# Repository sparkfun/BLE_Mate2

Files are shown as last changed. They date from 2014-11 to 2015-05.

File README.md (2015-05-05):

SparkFun BLE Mate 2
========================================

SparkFun BLE Mate 2

[*SparkFun BLE Mate 2 (WRL-13019)*](https://www.sparkfun.com/products/13019)

Repository Contents
-------------------

* **/Arduino** - All Arduino libraries and board examples
* **/Hardware** - All Eagle design files (.brd, .sch)
* **/Production** - Test bed files and production panel files

Version History
---------------
* [vH10L1.0.0](https://github.com/sparkfun/BLE_Mate2/tree/vH10L1.0.0) - Product version 10, library 1.0.0

License Information
-------------------
The hardware is released under [Creative Commons ShareAlike 4.0 International](https://creativecommons.org/licenses/by-sa/4.0/).
The code is beerware; if you see me (or any other SparkFun employee) at the local, and you've found our code helpful, please buy us a round!

Distributed as-is; no warranty is given.

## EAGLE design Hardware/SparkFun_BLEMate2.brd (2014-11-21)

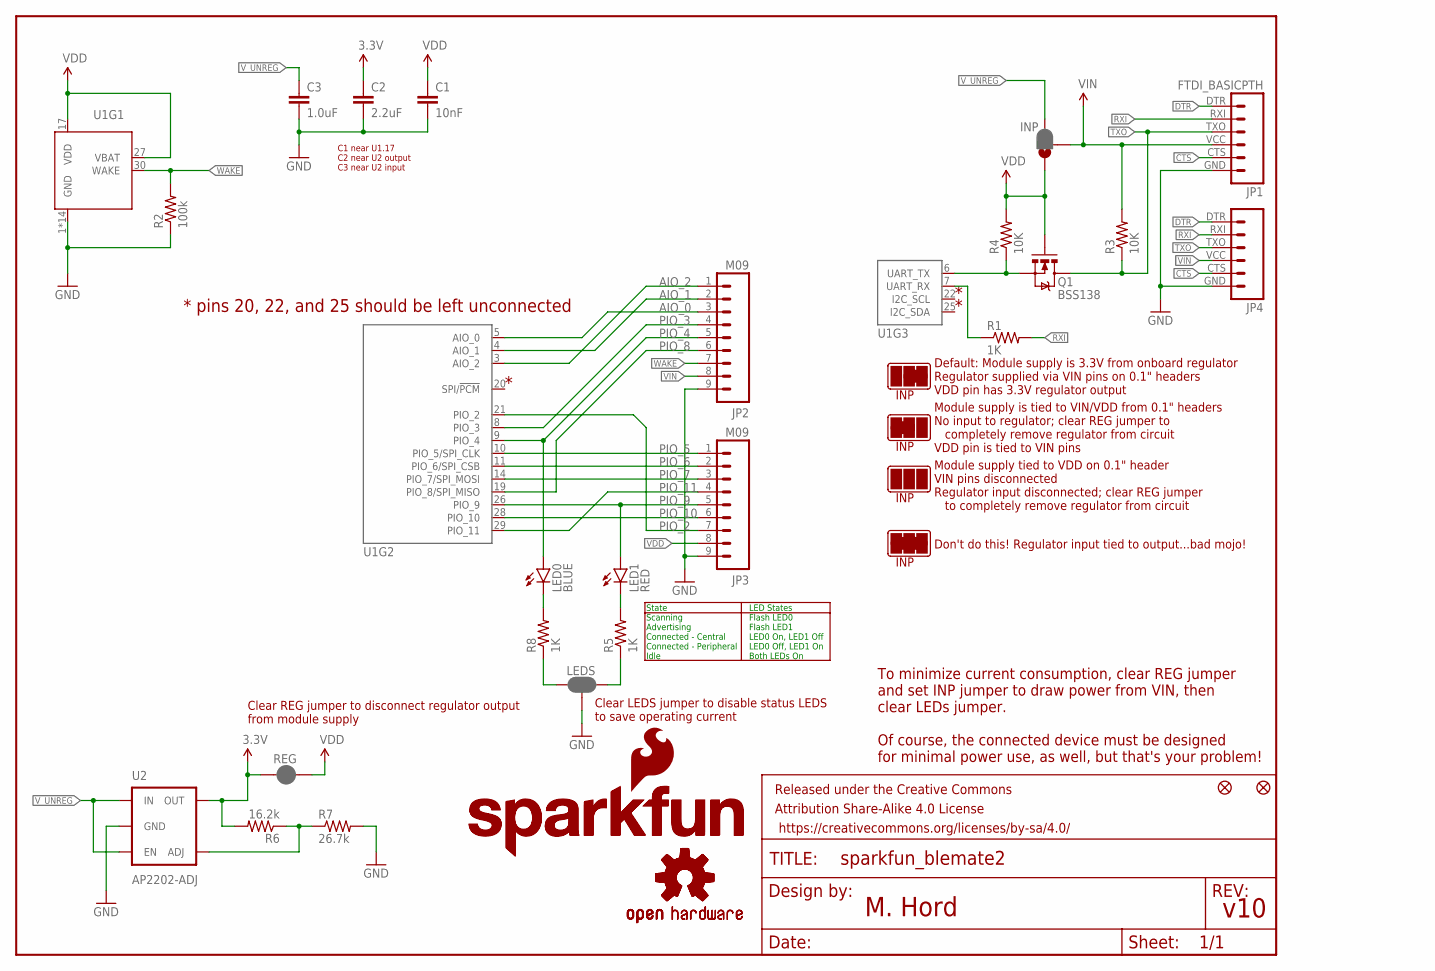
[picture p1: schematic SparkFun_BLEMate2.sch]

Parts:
C1: 10nF; 0603-CAP
C2: 2.2uF; 0603-CAP
C3: 1.0uF; 0603-CAP
FID1, FID2: FIDUCIAL1X2; FIDUCIAL-1X2
FRAME1: FRAME-LETTER; CREATIVE_COMMONS
INP: JUMPER-PAD-3-2OF3_NC_BY_PASTE; PAD-JUMPER-3-2OF3_NC_BY_PASTE_YES_SILK_FULL_BOX
JP1: FTDI_BASICPTH; FTDI_BASIC
JP2, JP3: M09; 1X09
JP4: M06SIP; 1X06
LED0: BLUE; LED-0603
LED1: RED; LED-0603
LEDS: JUMPER-PAD-3-NC_BY_PASTE; PAD-JUMPER-3-NC_BY_PASTE_YES_SILK_FULL_BOX
LOGO1: SFE_LOGO_NAME.1_INCH; SFE_LOGO_NAME_.1
LOGO2, LOGO4: OSHW-LOGOS; OSHW-LOGO-S
LOGO3: SFE_LOGO_NAME_FLAME.1_INCH; SFE_LOGO_NAME_FLAME_.1
Q1: BSS138; SOT23
R1, R5, R8: 1K; 0603-RES
R2: 100k; 0603-RES
R3, R4: 10K; 0603-RES
R6: 16.2k; 0603-RES
R7: 26.7k; 0603-RES
REG: JUMPER-PAD-2-NC_BY_PASTE; PAD-JUMPER-2-NC_BY_PASTE_YES_SILK
U1: BC118
U2: AP2202-ADJ; SOT23-5

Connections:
3.3V: C2.1, R6.2, REG.1, U2.5 (OUT)
AIO_0: JP2.3, U1.5 (AIO_0)
AIO_1: JP2.2, U1.4 (AIO_1)
AIO_2: JP2.1, U1.3 (AIO_2)
CTS: JP1.CTS (5), JP4.CTS (5)
DTR: JP1.DTR (1), JP4.DTR (1)
GND: C1.2, C2.2, C3.2, JP1.GND (6), JP2.9, JP3.9, JP4.GND (6), LEDS.2, R2.1, R7.2, U1.1 (GND), U1.2 (GND), U1.12 (GND), U1.13 (GND), U1.15 (GND), U1.16 (GND), U1.18 (GND), U1.23 (GND), U1.24 (GND), U1.31 (GND), U1.32 (GND), U1.33 (GND), U1.34 (GND), U1.35 (GND), U2.2 (GND)
unnamed: R1.1, U1.7 (UART_RX)
unnamed: R6.1, R7.1, U2.4 (ADJ)
unnamed: Q1.2 (S), R4.1, U1.6 (UART_TX)
unnamed: LEDS.1, R8.1
unnamed: LEDS.3, R5.1
unnamed: LED0.C, R8.2
unnamed: LED1.C, R5.2
PIO_2: JP3.7, U1.21 (PIO_2)
PIO_3: JP2.4, U1.8 (PIO_3)
PIO_4: JP2.5, LED0.A, U1.9 (PIO_4)
PIO_5: JP3.1, U1.10 (PIO_5/SPI_CLK)
PIO_6: JP3.2, U1.11 (PIO_6/SPI_CSB)
PIO_7: JP3.3, U1.14 (PIO_7/SPI_MOSI)
PIO_8: JP2.6, U1.19 (PIO_8/SPI_MISO)
PIO_9: JP3.5, LED1.A, U1.26 (PIO_9)
PIO_10: JP3.6, U1.28 (PIO_10)
PIO_11: JP3.4, U1.29 (PIO_11)
RXI: JP1.RXI (2), JP4.RXI (2), R1.2
TXO: JP1.TXO (3), JP4.TXO (3), Q1.3 (D), R3.1
VDD: C1.1, INP.1, JP3.8, Q1.1 (G), R4.2, REG.2, U1.17 (VDD), U1.27 (VBAT)
VIN: INP.2, JP1.VCC (4), JP2.8, JP4.VCC (4), R3.2
V_UNREG: C3.1, INP.3, U2.1 (IN), U2.3 (EN)
WAKE: JP2.7, R2.2, U1.30 (WAKE)

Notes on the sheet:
State Scanning Advertising Connected - Central Connected - Peripheral Idle
LED States Flash LED0 Flash LED1 LED0 On, LED1 Off LED0 Off, LED1 On Both LEDs On
C1 near U1.17 C2 near U2 output C3 near U2 input
INP
Default: Module supply is 3.3V from onboard regulator Regulator supplied via VIN pins on 0.1" headers VDD pin has 3.3V regulator output
Module supply is tied to VIN/VDD from 0.1" headers No input to regulator; clear REG jumper to completely remove regulator from circuit VDD pin is tied to VIN pins
Module supply tied to VDD on 0.1" header VIN pins disconnected Regulator input disconnected; clear REG jumper to completely remove regulator from circuit
Don't do this! Regulator input tied to output...bad mojo!
Clear LEDS jumper to disable status LEDS to save operating current
Clear REG jumper to disconnect regulator output from module supply
* pins 20, 22, and 25 should be left unconnected
To minimize current consumption, clear REG jumper and set INP jumper to draw power from VIN, then clear LEDs jumper. Of course, the connected device must be designed for minimal power use, as well, but that's your problem!
M. Hord
v10

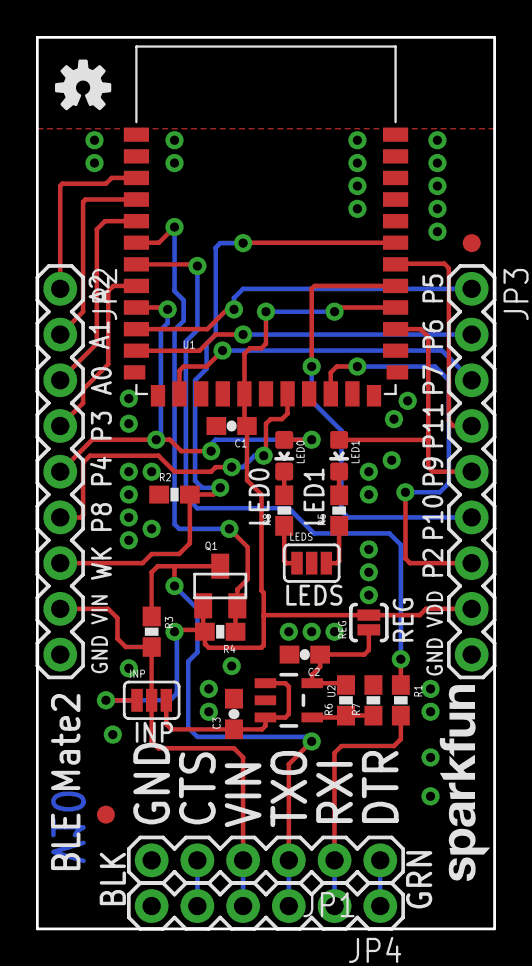
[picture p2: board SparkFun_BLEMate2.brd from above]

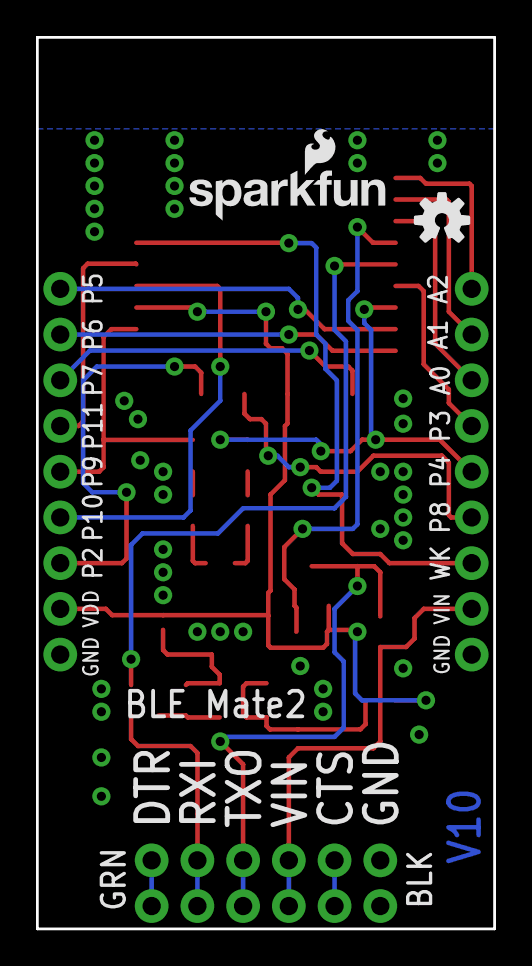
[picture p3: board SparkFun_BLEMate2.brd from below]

Board: 2 copper layers, 25.4 x 49.5 mm, 30 parts (2 on the bottom side), 30 nets.

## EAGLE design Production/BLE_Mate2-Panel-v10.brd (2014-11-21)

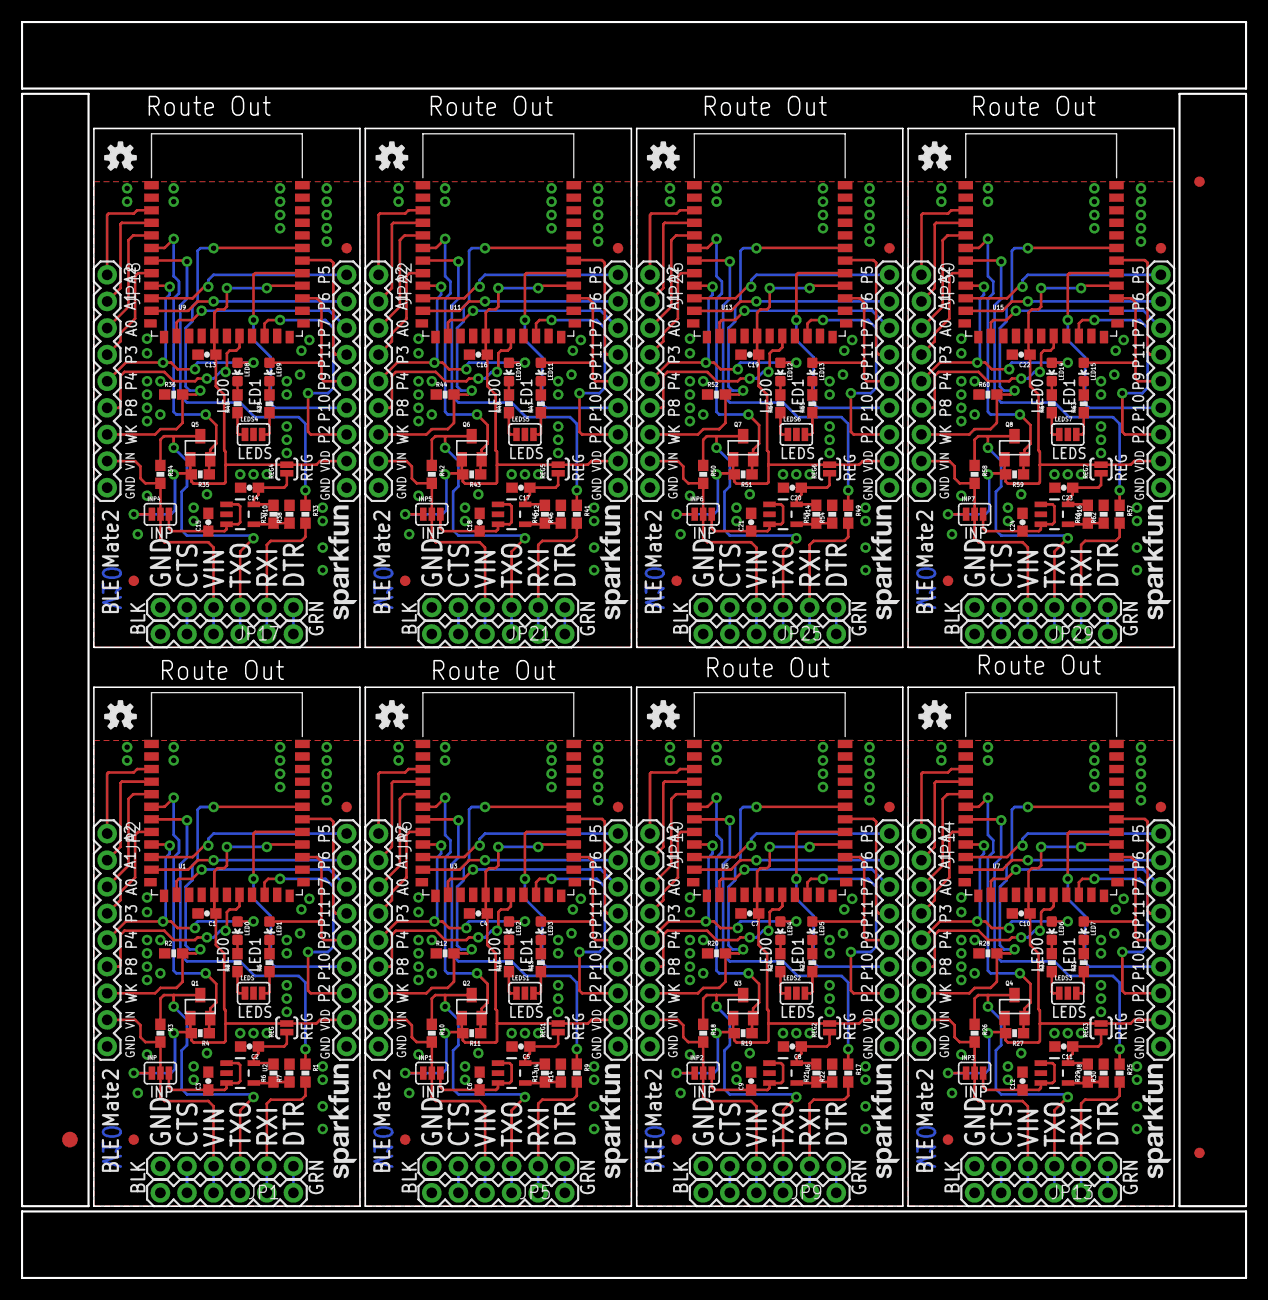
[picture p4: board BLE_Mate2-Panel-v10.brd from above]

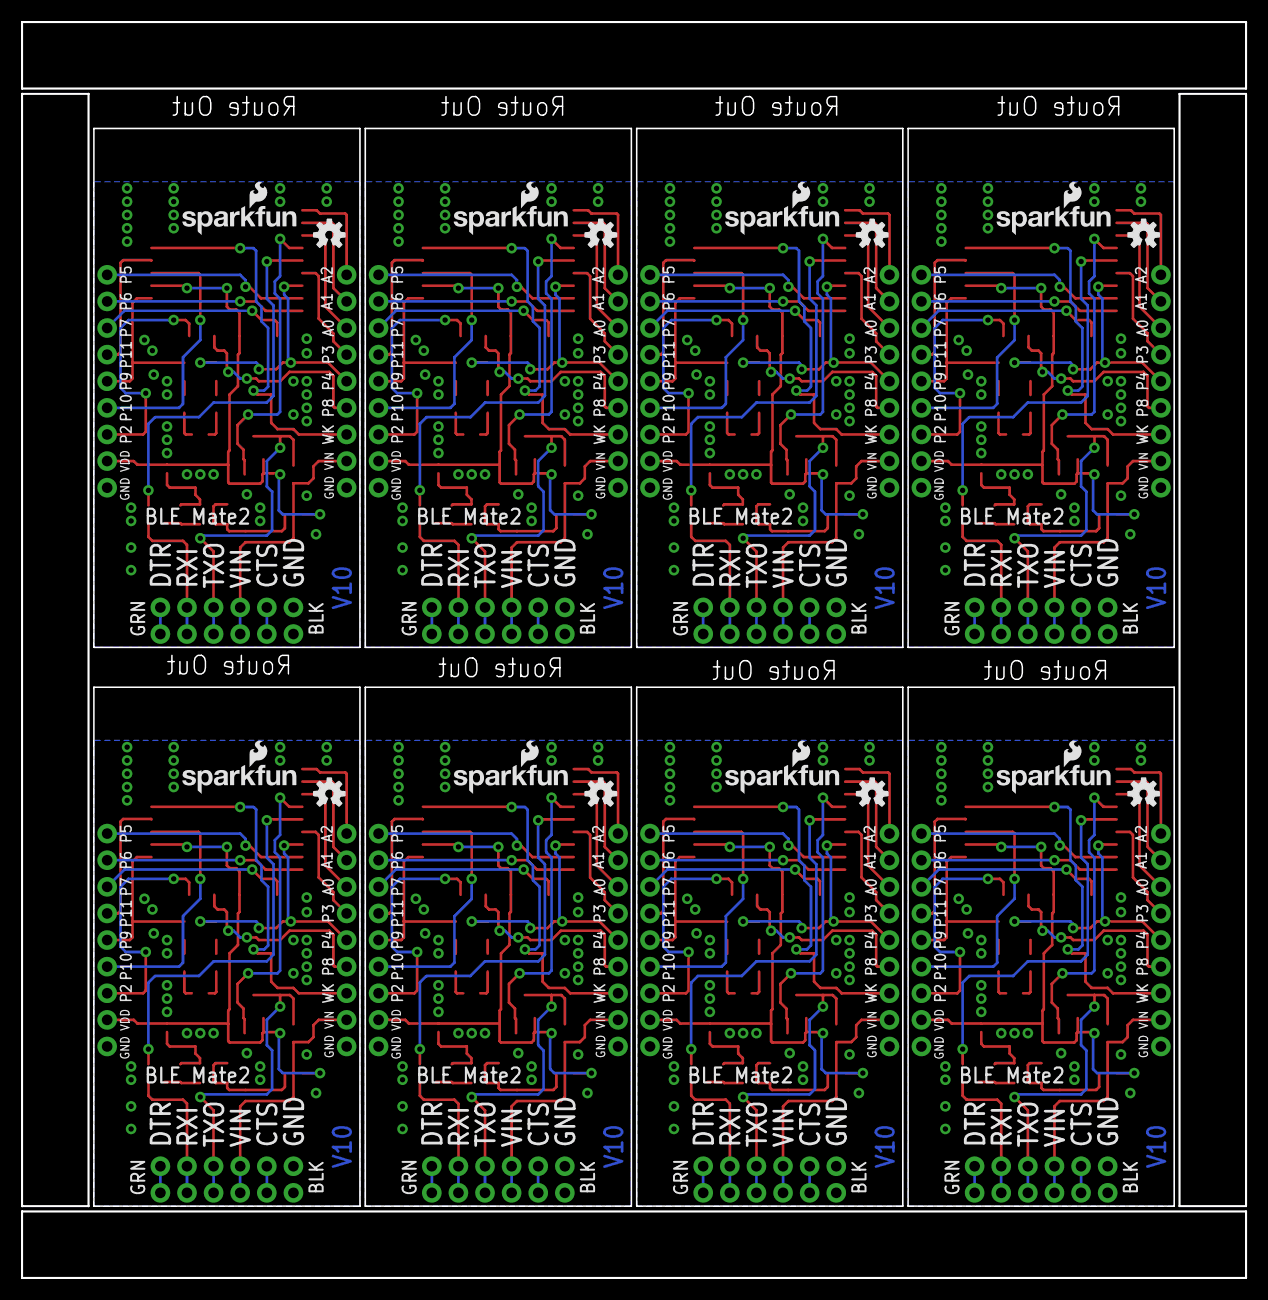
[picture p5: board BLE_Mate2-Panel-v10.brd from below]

Board: 2 copper layers, 116.8 x 119.9 mm, 235 parts (16 on the bottom side), 240 nets.

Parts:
C1, C4, C7, C10, C13, C16, C19, C22: 10nF; 0603-CAP
C2, C5, C8, C11, C14, C17, C20, C23: 2.2uF; 0603-CAP
C3, C6, C9, C12, C15, C18, C21, C24: 1.0uF; 0603-CAP
E$1: FIDUCIAL-1.5X3
E$4, E$5: FIDUCIAL-1X2
FID1, FID2, FID3, FID4, FID5, FID6, FID7, FID8, FID9, FID10, FID11, FID12, FID13, FID14, FID15, FID16: FIDUCIAL1X2; FIDUCIAL-1X2
INP, INP1, INP2, INP3, INP4, INP5, INP6, INP7: JUMPER-PAD-3-2OF3_NC_BY_PASTE; PAD-JUMPER-3-2OF3_NC_BY_PASTE_YES_SILK_FULL_BOX
JP1, JP5, JP9, JP13, JP17, JP21, JP25, JP29: FTDI_BASICPTH; FTDI_BASIC
JP2, JP3, JP6, JP7, JP10, JP11, JP14, JP15, JP18, JP19, JP22, JP23, JP26, JP27, JP30, JP31: M09; 1X09
JP4, JP8, JP12, JP16, JP20, JP24, JP28, JP32: 1X06
LED0, LED2, LED4, LED6, LED8, LED10, LED12, LED14: BLUE; LED-0603
LED1, LED3, LED5, LED7, LED9, LED11, LED13, LED15: RED; LED-0603
LEDS, LEDS1, LEDS2, LEDS3, LEDS4, LEDS5, LEDS6, LEDS7: JUMPER-PAD-3-NC_BY_PASTE; PAD-JUMPER-3-NC_BY_PASTE_YES_SILK_FULL_BOX
LOGO1, LOGO5, LOGO9, LOGO13, LOGO17, LOGO21, LOGO25, LOGO29: SFE_LOGO_NAME.1_INCH; SFE_LOGO_NAME_.1
LOGO2, LOGO4, LOGO6, LOGO8, LOGO10, LOGO12, LOGO14, LOGO16, LOGO18, LOGO20, LOGO22, LOGO24, LOGO26, LOGO28, LOGO30, LOGO32: OSHW-LOGOS; OSHW-LOGO-S
LOGO3, LOGO7, LOGO11, LOGO15, LOGO19, LOGO23, LOGO27, LOGO31: SFE_LOGO_NAME_FLAME.1_INCH; SFE_LOGO_NAME_FLAME_.1
Q1, Q2, Q3, Q4, Q5, Q6, Q7, Q8: BSS138; SOT23
R1, R5, R8, R9, R15, R16, R17, R23, R24, R25, R31, R32, R33, R39, R40, R41, R47, R48, R49, R55, R56, R57, R63, R64: 1K; 0603-RES
R2, R12, R20, R28, R36, R44, R52, R60: 100k; 0603-RES
R3, R4, R10, R11, R18, R19, R26, R27, R34, R35, R42, R43, R50, R51, R58, R59: 10K; 0603-RES
R6, R13, R21, R29, R37, R45, R53, R61: 16.2k; 0603-RES
R7, R14, R22, R30, R38, R46, R54, R62: 26.7k; 0603-RES
REG, REG1, REG2, REG3, REG4, REG5, REG6, REG7: JUMPER-PAD-2-NC_BY_PASTE; PAD-JUMPER-2-NC_BY_PASTE_YES_SILK
U1, U3, U5, U7, U9, U11, U13, U15: BC118
U2, U4, U6, U8, U10, U12, U14, U16: AP2202-ADJ; SOT23-5

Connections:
3.3V: C2.1, R6.2, REG.1, U2.5
3.3V1: C5.1, R13.2, REG1.1, U4.5
3.3V2: C8.1, R21.2, REG2.1, U6.5
3.3V3: C11.1, R29.2, REG3.1, U8.5
3.3V4: C14.1, R37.2, REG4.1, U10.5
3.3V5: C17.1, R45.2, REG5.1, U12.5
3.3V6: C20.1, R53.2, REG6.1, U14.5
3.3V7: C23.1, R61.2, REG7.1, U16.5
AIO_0: JP2.3, U1.5
AIO_1: JP2.2, U1.4
AIO_2: JP2.1, U1.3
AIO_3: JP6.1, U3.3
AIO_4: JP6.2, U3.4
AIO_5: JP6.3, U3.5
AIO_6: JP10.1, U5.3
AIO_7: JP10.2, U5.4
AIO_8: JP10.3, U5.5
AIO_9: JP14.1, U7.3
AIO_10: JP14.2, U7.4
AIO_11: JP14.3, U7.5
AIO_12: JP18.1, U9.3
AIO_13: JP18.2, U9.4
AIO_14: JP18.3, U9.5
AIO_15: JP22.1, U11.3
AIO_16: JP22.2, U11.4
AIO_17: JP22.3, U11.5
AIO_18: JP26.1, U13.3
AIO_19: JP26.2, U13.4
AIO_20: JP26.3, U13.5
AIO_21: JP30.1, U15.3
AIO_22: JP30.2, U15.4
AIO_23: JP30.3, U15.5
CTS: JP1.CTS, JP4.CTS
CTS1: JP5.CTS, JP8.CTS
CTS2: JP9.CTS, JP12.CTS
CTS3: JP13.CTS, JP16.CTS
CTS4: JP17.CTS, JP20.CTS
CTS5: JP21.CTS, JP24.CTS
CTS6: JP25.CTS, JP28.CTS
CTS7: JP29.CTS, JP32.CTS
DTR: JP1.DTR, JP4.DTR
DTR1: JP5.DTR, JP8.DTR
DTR2: JP9.DTR, JP12.DTR
DTR3: JP13.DTR, JP16.DTR
DTR4: JP17.DTR, JP20.DTR
DTR5: JP21.DTR, JP24.DTR
DTR6: JP25.DTR, JP28.DTR
DTR7: JP29.DTR, JP32.DTR
GND: C1.2, C2.2, C3.2, JP1.GND, JP2.9, JP3.9, JP4.GND, LEDS.2, R2.1, R7.2, U1.1, U1.2, U1.12, U1.13, U1.15, U1.16, U1.18, U1.23, U1.24, U1.31, U1.32, U1.33, U1.34, U1.35, U2.2
GND1: C4.2, C5.2, C6.2, JP5.GND, JP6.9, JP7.9, JP8.GND, LEDS1.2, R12.1, R14.2, U3.1, U3.2, U3.12, U3.13, U3.15, U3.16, U3.18, U3.23, U3.24, U3.31, U3.32, U3.33, U3.34, U3.35, U4.2
GND2: C7.2, C8.2, C9.2, JP9.GND, JP10.9, JP11.9, JP12.GND, LEDS2.2, R20.1, R22.2, U5.1, U5.2, U5.12, U5.13, U5.15, U5.16, U5.18, U5.23, U5.24, U5.31, U5.32, U5.33, U5.34, U5.35, U6.2
GND3: C10.2, C11.2, C12.2, JP13.GND, JP14.9, JP15.9, JP16.GND, LEDS3.2, R28.1, R30.2, U7.1, U7.2, U7.12, U7.13, U7.15, U7.16, U7.18, U7.23, U7.24, U7.31, U7.32, U7.33, U7.34, U7.35, U8.2
GND4: C13.2, C14.2, C15.2, JP17.GND, JP18.9, JP19.9, JP20.GND, LEDS4.2, R36.1, R38.2, U9.1, U9.2, U9.12, U9.13, U9.15, U9.16, U9.18, U9.23, U9.24, U9.31, U9.32, U9.33, U9.34, U9.35, U10.2
GND5: C16.2, C17.2, C18.2, JP21.GND, JP22.9, JP23.9, JP24.GND, LEDS5.2, R44.1, R46.2, U11.1, U11.2, U11.12, U11.13, U11.15, U11.16, U11.18, U11.23, U11.24, U11.31, U11.32, U11.33, U11.34, U11.35, U12.2
GND6: C19.2, C20.2, C21.2, JP25.GND, JP26.9, JP27.9, JP28.GND, LEDS6.2, R52.1, R54.2, U13.1, U13.2, U13.12, U13.13, U13.15, U13.16, U13.18, U13.23, U13.24, U13.31, U13.32, U13.33, U13.34, U13.35, U14.2
GND7: C22.2, C23.2, C24.2, JP29.GND, JP30.9, JP31.9, JP32.GND, LEDS7.2, R60.1, R62.2, U15.1, U15.2, U15.12, U15.13, U15.15, U15.16, U15.18, U15.23, U15.24, U15.31, U15.32, U15.33, U15.34, U15.35, U16.2
unnamed: R13.1, R14.1, U4.4
unnamed: R1.1, U1.7
unnamed: R6.1, R7.1, U2.4
unnamed: Q1.2, R4.1, U1.6
unnamed: LEDS.1, R8.1
unnamed: LEDS.3, R5.1
unnamed: Q2.2, R11.1, U3.6
unnamed: LED0.C, R8.2
unnamed: LED1.C, R5.2
unnamed: R9.1, U3.7
unnamed: LEDS1.1, R16.1
unnamed: LEDS1.3, R15.1
unnamed: LED2.C, R16.2
unnamed: LED3.C, R15.2
unnamed: R21.1, R22.1, U6.4
unnamed: Q3.2, R19.1, U5.6
unnamed: R17.1, U5.7
unnamed: LEDS2.1, R24.1
unnamed: LEDS2.3, R23.1
unnamed: LED4.C, R24.2
unnamed: LED5.C, R23.2
unnamed: R29.1, R30.1, U8.4
unnamed: Q4.2, R27.1, U7.6
unnamed: R25.1, U7.7
unnamed: LEDS3.1, R32.1
unnamed: LEDS3.3, R31.1
unnamed: LED6.C, R32.2
unnamed: LED7.C, R31.2
unnamed: R37.1, R38.1, U10.4
unnamed: Q5.2, R35.1, U9.6
unnamed: R33.1, U9.7
unnamed: LEDS4.1, R40.1
unnamed: LEDS4.3, R39.1
unnamed: LED8.C, R40.2
unnamed: LED9.C, R39.2
unnamed: R45.1, R46.1, U12.4
unnamed: Q6.2, R43.1, U11.6
unnamed: R41.1, U11.7
unnamed: LEDS5.1, R48.1
unnamed: LEDS5.3, R47.1
unnamed: LED10.C, R48.2
unnamed: LED11.C, R47.2
unnamed: R53.1, R54.1, U14.4
unnamed: Q7.2, R51.1, U13.6
unnamed: R49.1, U13.7
unnamed: LEDS6.1, R56.1
unnamed: LEDS6.3, R55.1
unnamed: LED12.C, R56.2
unnamed: LED13.C, R55.2
unnamed: R61.1, R62.1, U16.4
unnamed: Q8.2, R59.1, U15.6
unnamed: R57.1, U15.7
unnamed: LEDS7.1, R64.1
unnamed: LEDS7.3, R63.1
unnamed: LED14.C, R64.2
unnamed: LED15.C, R63.2
PIO_1: JP7.6, U3.28
PIO_2: JP3.7, U1.21
PIO_3: JP2.4, U1.8
PIO_4: JP2.5, LED0.A, U1.9
PIO_5: JP3.1, U1.10
PIO_6: JP3.2, U1.11
PIO_7: JP3.3, U1.14
PIO_8: JP2.6, U1.19
PIO_9: JP3.5, LED1.A, U1.26
PIO_10: JP3.6, U1.28
PIO_11: JP3.4, U1.29
PIO_12: JP7.5, LED3.A, U3.26
PIO_13: JP7.3, U3.14
PIO_14: JP7.2, U3.11
PIO_15: JP7.1, U3.10
PIO_16: JP6.5, LED2.A, U3.9
PIO_17: JP6.4, U3.8
PIO_18: JP7.7, U3.21
PIO_19: JP7.4, U3.29
PIO_20: JP6.6, U3.19
PIO_21: JP11.6, U5.28
PIO_22: JP11.5, LED5.A, U5.26
PIO_23: JP11.3, U5.14
PIO_24: JP11.2, U5.11
PIO_25: JP11.1, U5.10
PIO_26: JP10.5, LED4.A, U5.9
PIO_27: JP10.4, U5.8
PIO_28: JP11.7, U5.21
PIO_29: JP11.4, U5.29
PIO_30: JP10.6, U5.19
PIO_31: JP15.6, U7.28
PIO_32: JP15.5, LED7.A, U7.26
PIO_33: JP15.3, U7.14
PIO_34: JP15.2, U7.11
PIO_35: JP15.1, U7.10
PIO_36: JP14.5, LED6.A, U7.9
PIO_37: JP14.4, U7.8
PIO_38: JP15.7, U7.21
PIO_39: JP15.4, U7.29
PIO_40: JP14.6, U7.19
PIO_41: JP19.6, U9.28
PIO_42: JP19.5, LED9.A, U9.26
PIO_43: JP19.3, U9.14
PIO_44: JP19.2, U9.11
PIO_45: JP19.1, U9.10
PIO_46: JP18.5, LED8.A, U9.9
PIO_47: JP18.4, U9.8
PIO_48: JP19.7, U9.21
PIO_49: JP19.4, U9.29
PIO_50: JP18.6, U9.19
PIO_51: JP23.6, U11.28
PIO_52: JP23.5, LED11.A, U11.26
PIO_53: JP23.3, U11.14
PIO_54: JP23.2, U11.11
PIO_55: JP23.1, U11.10
PIO_56: JP22.5, LED10.A, U11.9
PIO_57: JP22.4, U11.8
PIO_58: JP23.7, U11.21
PIO_59: JP23.4, U11.29
PIO_60: JP22.6, U11.19
PIO_61: JP27.6, U13.28
PIO_62: JP27.5, LED13.A, U13.26
PIO_63: JP27.3, U13.14
PIO_64: JP27.2, U13.11
PIO_65: JP27.1, U13.10
PIO_66: JP26.5, LED12.A, U13.9
PIO_67: JP26.4, U13.8
PIO_68: JP27.7, U13.21
PIO_69: JP27.4, U13.29
PIO_70: JP26.6, U13.19
PIO_71: JP31.6, U15.28
PIO_72: JP31.5, LED15.A, U15.26
PIO_73: JP31.3, U15.14
PIO_74: JP31.2, U15.11
PIO_75: JP31.1, U15.10
PIO_76: JP30.5, LED14.A, U15.9
PIO_77: JP30.4, U15.8
PIO_78: JP31.7, U15.21
PIO_79: JP31.4, U15.29
PIO_80: JP30.6, U15.19
RXI: JP1.RXI, JP4.RXI, R1.2
RXI1: JP5.RXI, JP8.RXI, R9.2
RXI2: JP9.RXI, JP12.RXI, R17.2
RXI3: JP13.RXI, JP16.RXI, R25.2
RXI4: JP17.RXI, JP20.RXI, R33.2
RXI5: JP21.RXI, JP24.RXI, R41.2
RXI6: JP25.RXI, JP28.RXI, R49.2
RXI7: JP29.RXI, JP32.RXI, R57.2
TXO: JP1.TXO, JP4.TXO, Q1.3, R3.1
TXO1: JP5.TXO, JP8.TXO, Q2.3, R10.1
TXO2: JP9.TXO, JP12.TXO, Q3.3, R18.1
TXO3: JP13.TXO, JP16.TXO, Q4.3, R26.1
TXO4: JP17.TXO, JP20.TXO, Q5.3, R34.1
TXO5: JP21.TXO, JP24.TXO, Q6.3, R42.1
TXO6: JP25.TXO, JP28.TXO, Q7.3, R50.1
TXO7: JP29.TXO, JP32.TXO, Q8.3, R58.1
VDD: C1.1, INP.1, JP3.8, Q1.1, R4.2, REG.2, U1.17, U1.27
VDD1: C4.1, INP1.1, JP7.8, Q2.1, R11.2, REG1.2, U3.17, U3.27
VDD2: C7.1, INP2.1, JP11.8, Q3.1, R19.2, REG2.2, U5.17, U5.27
VDD3: C10.1, INP3.1, JP15.8, Q4.1, R27.2, REG3.2, U7.17, U7.27
VDD4: C13.1, INP4.1, JP19.8, Q5.1, R35.2, REG4.2, U9.17, U9.27
VDD5: C16.1, INP5.1, JP23.8, Q6.1, R43.2, REG5.2, U11.17, U11.27
VDD6: C19.1, INP6.1, JP27.8, Q7.1, R51.2, REG6.2, U13.17, U13.27
VDD7: C22.1, INP7.1, JP31.8, Q8.1, R59.2, REG7.2, U15.17, U15.27
VIN: INP.2, JP1.VCC, JP2.8, JP4.VCC, R3.2
VIN1: INP1.2, JP5.VCC, JP6.8, JP8.VCC, R10.2
VIN2: INP2.2, JP9.VCC, JP10.8, JP12.VCC, R18.2
VIN3: INP3.2, JP13.VCC, JP14.8, JP16.VCC, R26.2
VIN4: INP4.2, JP17.VCC, JP18.8, JP20.VCC, R34.2
VIN5: INP5.2, JP21.VCC, JP22.8, JP24.VCC, R42.2
VIN6: INP6.2, JP25.VCC, JP26.8, JP28.VCC, R50.2
VIN7: INP7.2, JP29.VCC, JP30.8, JP32.VCC, R58.2
V_UNREG: C3.1, INP.3, U2.1, U2.3
V_UNREG1: C6.1, INP1.3, U4.1, U4.3
V_UNREG2: C9.1, INP2.3, U6.1, U6.3
V_UNREG3: C12.1, INP3.3, U8.1, U8.3
V_UNREG4: C15.1, INP4.3, U10.1, U10.3
V_UNREG5: C18.1, INP5.3, U12.1, U12.3
V_UNREG6: C21.1, INP6.3, U14.1, U14.3
V_UNREG7: C24.1, INP7.3, U16.1, U16.3
WAKE: JP2.7, R2.2, U1.30
WAKE1: JP6.7, R12.2, U3.30
WAKE2: JP10.7, R20.2, U5.30
WAKE3: JP14.7, R28.2, U7.30
WAKE4: JP18.7, R36.2, U9.30
WAKE5: JP22.7, R44.2, U11.30
WAKE6: JP26.7, R52.2, U13.30
WAKE7: JP30.7, R60.2, U15.30

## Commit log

2014-07-07 Initial commit.
    [BC118_Mate.brd, BC118_Mate.sch]
2014-07-14 V01 ready for protos
    [BC118_Mate.brd, BC118_Mate.sch]
2014-07-15 Update BC118 with part info
    [BC118_Mate.brd, BC118_Mate.sch]
2014-10-07 Change LED pin assignments to match new firmware
    [BC118_Mate.brd, BC118_Mate.sch]
2014-10-27 Ready for reds
    [BC118_Mate.brd, BC118_Mate.sch]
2014-10-27 Rename hardware files
    [BLE_Mate2.brd, BLE_Mate2.sch]
2014-10-27 added board fiducials
    [BLE_Mate2.brd, BLE_Mate2.sch]
2014-10-29 created panel v10
    [BLE_Mate2-Panel-v10.brd]
2014-11-21 Add example code, library.
    [BLE_Mate2.brd, BLE_Mate2.sch]
2014-11-21 Rename/restructure files to SFE standards
    [SparkFun_BLEMate2.brd, SparkFun_BLEMate2.sch]
2015-05-05 Renamed, restructured files
    [BLE_Mate2-Panel-v10.brd]
2015-05-05 Squashed 'Libraries/Arduino/' content from commit 2ead2d9
    git-subtree-dir: Libraries/Arduino
    git-subtree-split: 2ead2d9625ff02445bcaa97c111b7e216bf73175

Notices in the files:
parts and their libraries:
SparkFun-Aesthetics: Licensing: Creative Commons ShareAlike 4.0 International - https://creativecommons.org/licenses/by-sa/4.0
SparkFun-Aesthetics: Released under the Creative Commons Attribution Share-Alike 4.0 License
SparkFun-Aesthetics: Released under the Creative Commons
